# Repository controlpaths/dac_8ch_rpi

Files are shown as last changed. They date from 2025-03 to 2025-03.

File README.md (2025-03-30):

# 8-ch Analog output board

The DAC-8CH-RPI board features 8 analog outputs, 8 digital inputs and 4 digital outputs. It is intended to be used in real-time hardware simulators or signal generators. 

## Analog outputs

The board features an 8-channel DAC with a resolution of 12 bits, and a sampling rate of up to 100ksps. 

The output range goes from -3V to 3V.

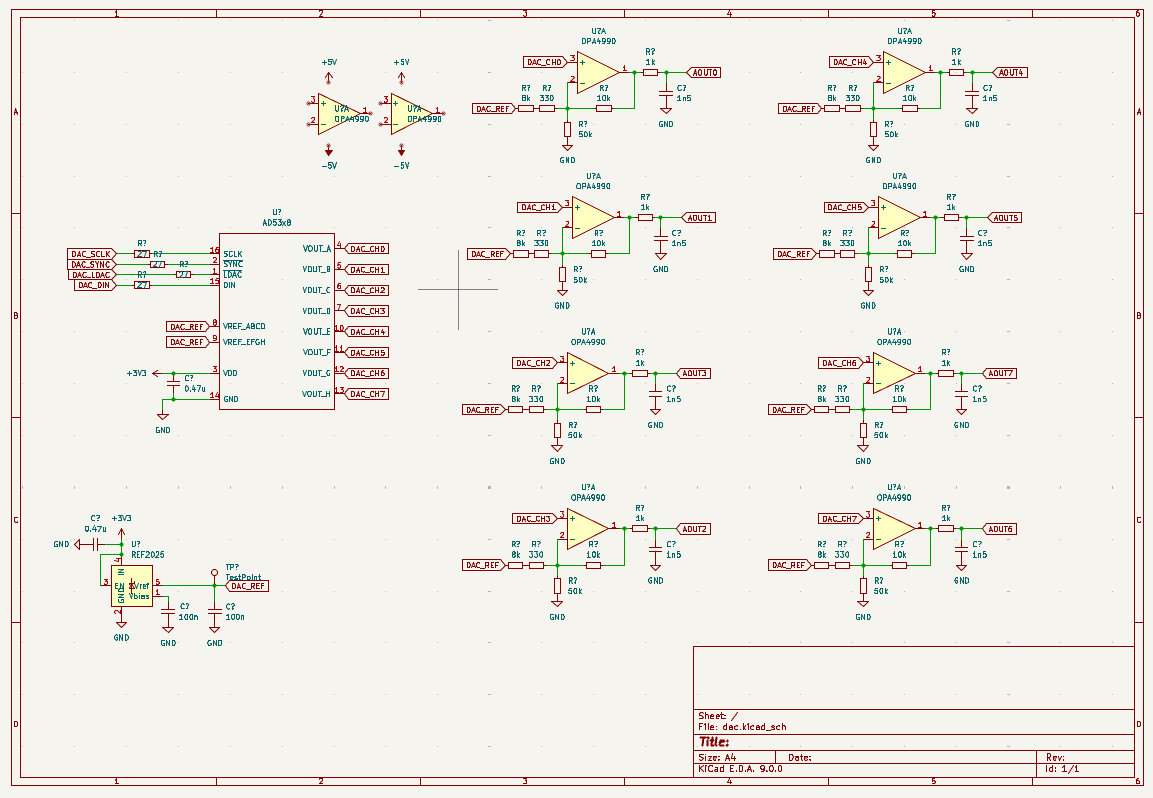
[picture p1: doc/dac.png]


## Raspberry Pi connector

The board features a 40-pin Raspberry PI Connector with the SPI interface for the DAc and the digital in-out.

This connector is compatible with FPGA boards such as Pynq-Z1, Pynq-Z2,AMD KR260 or MPFS Discovery Kit.

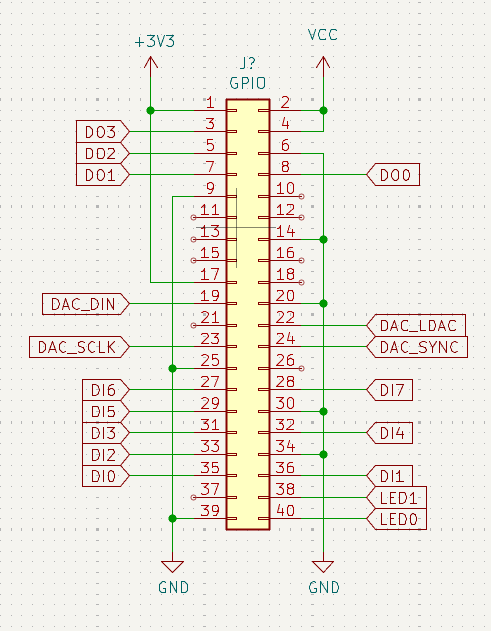
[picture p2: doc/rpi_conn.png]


## Get Yours

The RP2040 PMOD is open-source, so you can use the output files to manufacture your own in [JLCPCB](https://jlcpcb.com/?from=controlpath). You just need to compress the `production_files` directory, and upload it to [JLCPCB](https://jlcpcb.com/?from=controlpath). 

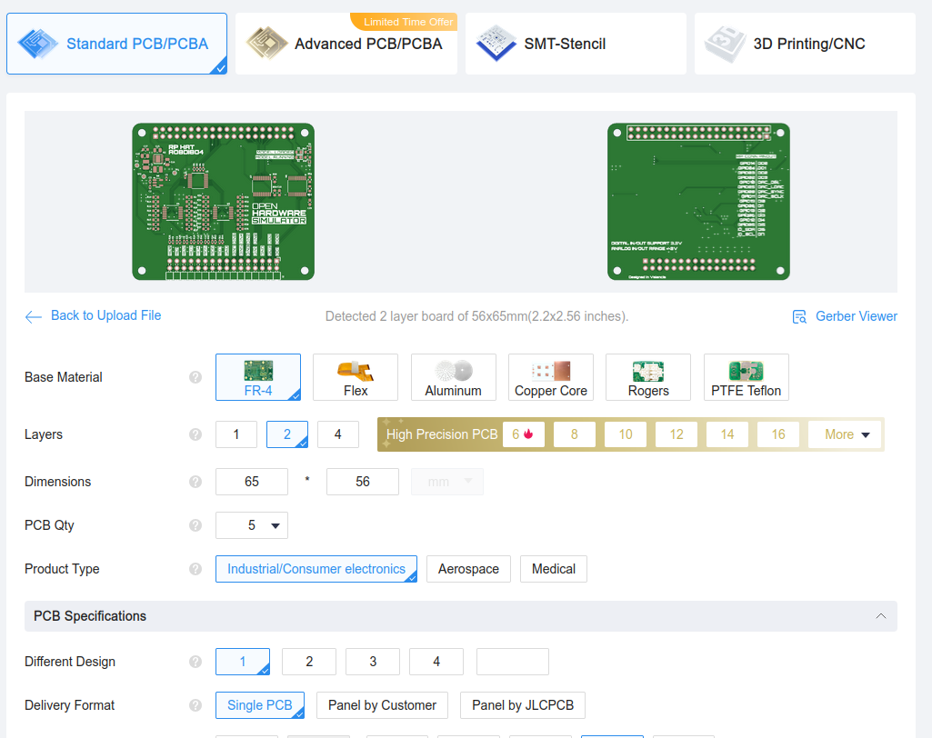
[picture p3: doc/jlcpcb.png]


Remember to change the Surface Finish to **LeadFree HASL** to make your board ROHS compliant.

Then you have to add the PCB Assembly service and upload the [centroid](./kicad/production_files/ohsim_hat_pos.csv) file, and the [BOM](./kicad/production_files/bom.csv). 

In a few days, you will receive your board at home.

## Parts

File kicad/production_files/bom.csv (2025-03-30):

Reference | Value | Footprint | Qty | JLCPCB Part #
C2,C4 | 0.47u | Capacitor_SMD:C_0402_1005Metric | 2 | C106255
C3,C5 | 100n | Capacitor_SMD:C_0402_1005Metric | 2 | C1525
C6,C7,C8,C9,C10,C11,C12,C13 | 1n5 | Capacitor_SMD:C_0402_1005Metric | 8 | C23967
C14,C15,C16 | 10u | Capacitor_SMD:C_0805_2012Metric | 3 | C86038
C17,C18,C19 | 100n | Capacitor_SMD:C_0603_1608Metric | 3 | C1590
D1,D2 | LED | LED_SMD:LED_0603_1608Metric | 2 | C2288
J1 | GPIO | Connector_PinSocket_2.54mm:PinSocket_2x20_P2.54mm_Vertical | 1 | C50982
J2 | Conn_02x16_Odd_Even | Connector_PinHeader_2.54mm:PinHeader_2x16_P2.54mm_Horizontal | 1 | C97095
L1,L2 | 4u7 | Inductor_SMD:L_1008_2520Metric | 2 | C882976
Q1,Q2 | DMN26D0UFB4-7 | Package_DFN_QFN:Diodes_DFN1006-3 | 2 | C7525126
R3,R4,R5,R6 | 27 | Resistor_SMD:R_0402_1005Metric | 4 | C25100
R7,R8,R9,R10,R27,R28,R29,R30 | 8k | Resistor_SMD:R_0603_1608Metric | 8 | C862311
R11,R12,R13,R14,R31,R32,R33,R34,R47,R48 | 330 | Resistor_SMD:R_0603_1608Metric | 10 | C22104
R15,R16,R17,R18,R35,R36,R37,R38 | 50k | Resistor_SMD:R_0603_1608Metric | 8 | C304067
R19,R20,R21,R22,R39,R40,R41,R42,R49,R50,R51,R52 | 10k | Resistor_SMD:R_0603_1608Metric | 12 | C15401
R23,R24,R25,R26,R43,R44,R45,R46 | 1k | Resistor_SMD:R_0402_1005Metric | 8 | C409681
U2 | ~ | Package_SON:WSON-12-1EP_3x3mm_P0.5mm_EP1.5x2.5mm | 1 | C134100
U3 | AD53x8 | Package_SO:TSSOP-16_4.4x5mm_P0.65mm | 1 | C578186
U4,U5 | OPA4990 | Package_SO:TSSOP-14_4.4x5mm_P0.65mm | 2 | C2862600
U6 | REF2025 | Package_TO_SOT_SMD:SOT-23-5 | 1 | C962078
U7,U8 | 74HC245 | Package_SO:TSSOP-20_4.4x6.5mm_P0.65mm | 2 | C37101

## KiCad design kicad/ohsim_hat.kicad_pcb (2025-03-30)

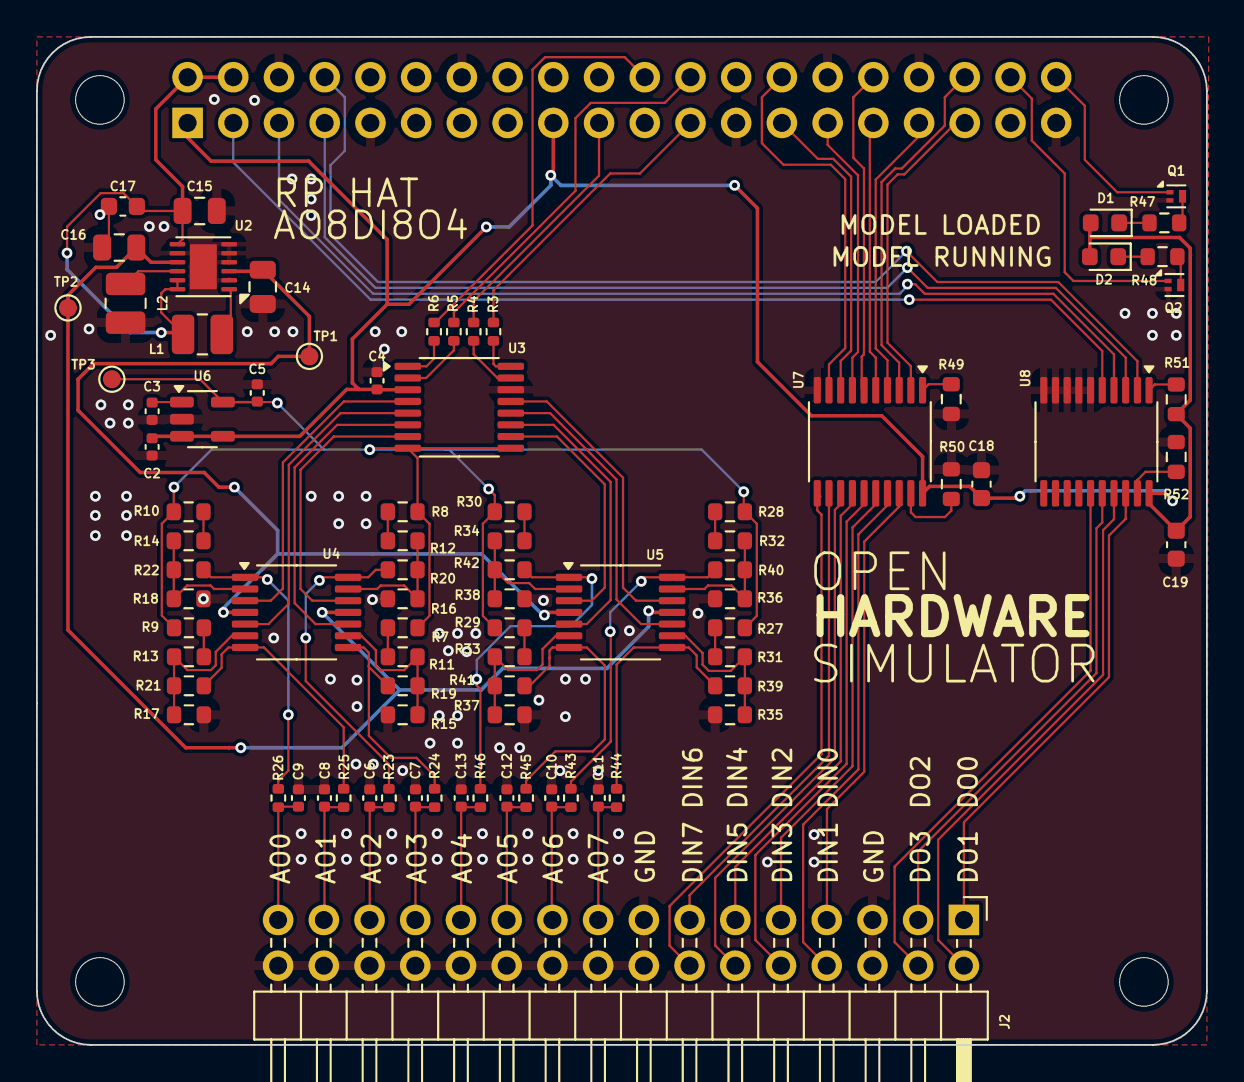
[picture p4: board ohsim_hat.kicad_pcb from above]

Board: 2 copper layers, 65.0 x 56.0 mm, 90 parts (1 on the bottom side), 91 nets.

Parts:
C2, C4: 0.47u; C_0402_1005Metric
C3, C5: 100n; C_0402_1005Metric
C6, C7, C8, C9, C10, C11, C12, C13: 1n5; C_0402_1005Metric
C14, C15, C16: 10u; C_0805_2012Metric
C17, C18, C19: 100n; C_0603_1608Metric
D1, D2: LED; LED_0603_1608Metric
J1: GPIO; PinSocket_2x20_P2.54mm_Vertical
J2: Conn_02x16_Odd_Even; PinHeader_2x16_P2.54mm_Horizontal
L1, L2: 4u7; L_1008_2520Metric
MH1, MH2, MH3, MH4: MountingHole_2.7mm_M2.5
Q1, Q2: DMN26D0UFB4-7; Diodes_DFN1006-3
R3, R4, R5, R6: 27; R_0402_1005Metric
R7, R8, R9, R10, R27, R28, R29, R30: 8k; R_0603_1608Metric
R11, R12, R13, R14, R31, R32, R33, R34, R47, R48: 330; R_0603_1608Metric
R15, R16, R17, R18, R35, R36, R37, R38: 50k; R_0603_1608Metric
R19, R20, R21, R22, R39, R40, R41, R42, R49, R50, R51, R52: 10k; R_0603_1608Metric
R23, R24, R25, R26, R43, R44, R45, R46: 1k; R_0402_1005Metric
TP1, TP2, TP3: TestPoint; TestPoint_Pad_D1.0mm
U2: WSON-12-1EP_3x3mm_P0.5mm_EP1.5x2.5mm
U3: AD53x8; TSSOP-16_4.4x5mm_P0.65mm
U4, U5: OPA4990; TSSOP-14_4.4x5mm_P0.65mm
U6: REF2025; SOT-23-5
U7, U8: 74HC245; TSSOP-20_4.4x6.5mm_P0.65mm

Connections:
+3V3: C2.2, C4.1, C18.2, C19.2, D1.2 (A), D2.2 (A), J1.1, J1.17, R51.1, U3.3 (VDD), U6.3 (EN), U6.4 (IN), U7.20 (VCC), U8.20 (VCC)
+5V: C14.1, TP1.1, U2.3 (VPOS), U4.4 (V+), U5.4 (V+)
-5V: C16.1, TP2.1, U2.9 (VNEG), U4.11 (V-), U5.11 (V-)
AOUT0: C9.1, J2.31, R26.2
AOUT1: C8.1, J2.29, R25.2
AOUT2: C6.1, J2.27, R23.2
AOUT3: C7.1, J2.25, R24.2
AOUT4: C13.1, J2.23, R46.2
AOUT5: C12.1, J2.21, R45.2
AOUT6: C10.1, J2.19, R43.2
AOUT7: C11.1, J2.17, R44.2
DAC_CH0: U3.4 (VOUT_A), U4.3 (+)
DAC_CH1: U3.5 (VOUT_B), U4.5 (+)
DAC_CH2: U3.6 (VOUT_C), U4.10 (+)
DAC_CH3: U3.7 (VOUT_D), U4.12 (+)
DAC_CH4: U3.10 (VOUT_E), U5.3 (+)
DAC_CH5: U3.11 (VOUT_F), U5.5 (+)
DAC_CH6: U3.12 (VOUT_G), U5.10 (+)
DAC_CH7: U3.13 (VOUT_H), U5.12 (+)
DAC_DIN: J1.19, R4.2
DAC_LDAC: J1.22, R6.2
DAC_REF: C5.1, R7.1, R8.1, R9.1, R10.1, R27.1, R28.1, R29.1, R30.1, TP3.1, U3.8 (VREF_ABCD), U3.9 (VREF_EFGH), U6.5 (Vref)
DAC_SCLK: J1.23, R3.2
DAC_SYNC: J1.24, R5.2
DI0: J1.35, U7.2 (A0)
DI0_CONN: J2.7, U7.18 (B0)
DI1: J1.36, U7.3 (A1)
DI1_CONN: J2.8, U7.17 (B1)
DI2: J1.33, U7.4 (A2)
DI2_CONN: J2.9, U7.16 (B2)
DI3: J1.31, U7.5 (A3)
DI3_CONN: J2.10, U7.15 (B3)
DI4: J1.32, U7.6 (A4)
DI4_CONN: J2.11, U7.14 (B4)
DI5: J1.29, U7.7 (A5)
DI5_CONN: J2.12, U7.13 (B5)
DI6: J1.27, U7.8 (A6)
DI6_CONN: J2.13, U7.12 (B6)
DI7: J1.28, U7.9 (A7)
DI7_CONN: J2.14, U7.11 (B7)
DO0: J1.8, U8.2 (A0)
DO0_CONN: J2.1, U8.18 (B0)
DO1: J1.7, U8.3 (A1)
DO1_CONN: J2.2, U8.17 (B1)
DO2: J1.5, U8.4 (A2)
DO2_CONN: J2.3, U8.16 (B2)
DO3: J1.3, U8.5 (A3)
DO3_CONN: J2.4, U8.15 (B3)
GND: C2.1, C3.2, C4.2, C5.2, C6.2, C7.2, C8.2, C9.2, C10.2, C11.2, C12.2, C13.2, C14.2, C15.2, C16.2, C17.2, C18.1, C19.1, J1.6, J1.9, J1.14, J1.20, J1.25, J1.30, J1.34, J1.39, J2.5, J2.6, J2.15, J2.16, J2.18, J2.20, J2.22, J2.24, J2.26, J2.28, J2.30, J2.32, L2.2, Q1.2, Q2.2, R15.1, R16.1, R17.1, R18.1, R35.1, R36.1, R37.1, R38.1, R49.1, R50.1, R52.1, U2.2 (PGND), U2.4 (GND), U2.5 (AGND), U2.6 (GND), U2.8 (GND), U2.13 (EP), U3.14 (GND), U6.2 (GND), U7.10 (GND), U8.6 (A4), U8.7 (A5), U8.8 (A6), U8.9 (A7), U8.10 (GND)
LED0: J1.40, Q1.1
LED1: J1.38, Q2.1
unnamed: D1.1 (K), R47.1
unnamed: D2.1 (K), R48.1
unnamed: Q1.3, R47.2
unnamed: Q2.3, R48.2
unnamed: R10.2, R14.1
unnamed: R7.2, R11.1
unnamed: R8.2, R12.1
unnamed: R9.2, R13.1
unnamed: R19.2, R24.1, U4.8
unnamed: R20.2, R23.1, U4.14
unnamed: R21.2, R25.1, U4.7
unnamed: R22.2, R26.1, U4.1
unnamed: R27.2, R31.1
unnamed: R28.2, R32.1
unnamed: R29.2, R33.1
unnamed: R30.2, R34.1
unnamed: R39.2, R44.1, U5.8
unnamed: R40.2, R43.1, U5.14
unnamed: R41.2, R45.1, U5.7
unnamed: R42.2, R46.1, U5.1
unnamed: L2.1, U2.10 (SWN)
unnamed: L1.2, U2.1 (SWP)
unnamed: R4.1, U3.15 (DIN)
unnamed: R3.1, U3.16 (SCLK)
unnamed: R6.1, U3.1 (~LDAC)
unnamed: R5.1, U3.2 (~SYNC)
unnamed: R14.2, R18.2, R22.1, U4.2 (-)
unnamed: R13.2, R17.2, R21.1, U4.6 (-)
unnamed: R11.2, R15.2, R19.1, U4.9 (-)
unnamed: R12.2, R16.2, R20.1, U4.13 (-)
unnamed: R34.2, R38.2, R42.1, U5.2 (-)
unnamed: R33.2, R37.2, R41.1, U5.6 (-)
unnamed: R31.2, R35.2, R39.1, U5.9 (-)
unnamed: R32.2, R36.2, R40.1, U5.13 (-)
unnamed: C3.1, U6.1 (Vbias)
unnamed: R49.2, U7.1 (A->B)
unnamed: R50.2, U7.19 (CE)
unnamed: R51.2, U8.1 (A->B)
unnamed: R52.2, U8.19 (CE)
VCC: C15.1, C17.1, J1.2, J1.4, L1.1, U2.7 (EN), U2.11 (AVIN), U2.12 (PVIN)
